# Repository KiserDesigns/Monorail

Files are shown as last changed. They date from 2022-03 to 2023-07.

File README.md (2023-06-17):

# Monorail V2

Version 2 is based on the RP2040 and has encoder positions on ESC, 1, and 6.

Plate files made up of the same outlines as are found in the Trashman Wiki, and enough permutations have been tested to be confident in their functionality.

More plate files can be found at https://www.minivanplate.xyz/

The "Combined" plates have support for all of the layouts from all three PCBs.

Vial firmware was built on this commit of the NCKiser fork of Vial, based on QMK v0.18 : https://github.com/NCKiser/vial-nckiser/commit/2a0371c2ef1b1343f7dda704ad11ff06da6e896c

# Build Guide

## What you need:
 - PCB (included)
 - Base (included)
 - Plate (included)
 - Hardware (included)
 - Philips (+) Screwdriver
 - Needle-nose Pliers (optional)



## Step 1: Standoffs
### There is the option to use Hull-mount, Tray-mount, or both at the same time!
### For Hull-mount, use brass washers on either side of the plate so the screw and 10mm standoff clamp firmly to the half-hole.

### Start with holding the screw and washer the top side, and then placing the washer and twisting on the standoff from the other side.



### Repeat this for the other 3 Hull-mount standoffs.

### For Tray-mount, attach the 5mm standoffs and washers to the base first, using the washer on the standoff side, not the screw side.



### Repeat this for all 8 Tray-mount point, or exclude certain points based on your desired typing feel.


## Step 2: PCB Assembly
### If using Tray-mount, it makes sense to screw the PCB to the base first.

### Snap switches into the PCB through the plate, starting with the center and outside corners.

### This is what the final stackup should look like:


## Step 3: Optional Part Removal
### The top half-numrow can be optionally removed for a 4-row layout or to fit in standard minivan cases.
### The half-numrow on the PCB and Base can be broken by hand:






### The plate will need to be separated using needle-nose pliers:





### If not using Hull-mount, the extra tabs can be removed using needle-nose pliers:





### If fitting the PCB into a V4N4G0N case, the right USB port may need to be removed.





### This will take a bit of force, and the USB port might be damaged while removing. That is okay.


## Stem 4: Firmware
### Vial firmware is pre-flashed on each PCB, and the default layout is hosted here.

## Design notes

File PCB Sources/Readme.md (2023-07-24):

Open in Kidac 6.0.10 or newer

Production files may need to be tweaked or re-computed before ordering from a PCB fabricator. Please use at your own risk, there is no guarantee of functionality.

Feel free to reach out to NoahK (kiserdesigns) on Discord (http://noahk.net) or through the Contact page on https://KiserDesigns.com if you would like help ordering these for yourself.

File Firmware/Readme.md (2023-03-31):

The keymap in the precompiled .uf2 is all KC_TRANS. Use Vial to configure your keymap.

DefaultLayout.vil is a Vial layout that contains most of the functionality that you need. Load this onto your board using Vial for a good starting point.

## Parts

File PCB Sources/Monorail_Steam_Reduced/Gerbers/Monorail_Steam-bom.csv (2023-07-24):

Id | Designator | Package | Quantity | Designation | Supplier and ref
1 | MX7,MX8,MX9,MX10,MX11,MX12,MX13,MX14,MX15,MX16,MX17,MX20,MX21,MX22,MX23,MX24,MX25,MX26,MX27,MX28,MX29,MX32,MX33,MX34,MX35,MX36,MX37,MX38,MX39,MX40,MX41,MX42,MX2,MX3,MX4,MX5,MX6,MX57,MX51,MX54,MX46,MX1,MX47 | MXOnly-1U-Hotswap | 43 | MX-NoLED
2 | MX18,MX31 | MXOnly-1.75U-Hotswap | 2 | MX-NoLED
3 | MX19,MX50,MX52,MX49,MX53,MX48 | MXOnly-1.25U-Hotswap | 6 | MX-NoLED
4 | MX30 | MXOnly-1.5U-Hotswap | 1 | MX-NoLED
5 | REF**,REF**,REF**,REF**,REF**,REF**,REF**,REF** | breakaway-mousebites | 8 | breakaway-mousebites
6 | MX44 | MXOnly-6.25U-Hotswap-ReversedStabilizers | 1 | MX-NoLED
7 | J10,J7 | PinHeader_1x09_P2.54mm_Vertical | 2 | Conn_01x09
8 | J9,J8 | PinHeader_1x05_P2.54mm_Vertical | 2 | Conn_01x05
9 | D55,D53,D54 | LED_D3.0mm | 3 | LED
10 |  |  | 1
11 | MX58,MX43 | MXOnly-3U-Hotswap-ReversedStabilizers | 2 | MX-NoLED
12 | SW3,SW2,SW1 | RotaryEncoder_Alps_EC11E-Switch_Vertical_H20mm | 3 | RotaryEncoder_Switch
13 | H1 | Minivan-reference | 1 | MountingHole_Pad
14 | MX45 | MXOnly-2.75U-Hotswap | 1 | MX-NoLED
15 | F1 | Fuse_1206_3216Metric | 1 | 500mA
16 | J1,J2 | USB_C_Receptacle_HRO_TYPE-C-31-M-12 | 2 | USB_C_Receptacle_USB2.0
17 | R4,R3,R1,R2 | R_0603_1608Metric | 4 | 5.1k
18 | R6,R7 | R_0402_1005Metric | 2 | 27
19 | U1 | SOT-23-6 | 1 | SRV05-4
20 | D33,D9,D27,D8,D28,D14,D18,D13,D16,D3,D51,D34,D44,D7,D22,D6,D11,D48,D41,D45,D52,D12,D17,D24,D47,D36,D30,D38,D31,D39,D10,D20,D1,D26,D4,D15,D2,D23,D40,D21,D50,D43,D25,D19,D29,D32,D35,D5,D37,D42 | D_SOD-123 | 50 | D_Small
21 | C9,C16,C10,C12,C18,C14,C15,C20,C17,C13,C19,C11 | C_0603_1608Metric | 12 | 0.1uF
22 | SWD1 | PinHeader_1x03_P2.54mm_Vertical | 1 | Conn_01x03_Female
23 | R14,R12 | R_0402_1005Metric | 2 | 1k
24 | D65,D61,D63,D66,D59,D58,D64,D62,D67,D60,D56,D57 | LED_WS2812B_2020 | 12 | WS2812B
25 | C6,C27 | C_0402_1005Metric | 2 | 30p
26 | C8,C28,C26,C22,C24,C21,C23,C7,C25 | C_0402_1005Metric | 9 | 100n
27 | J6 | PinHeader_1x03_P2.54mm_Vertical | 1 | Conn_01x03_Male
28 | R13 | R_0603_1608Metric | 1 | -10k
29 | R11,R9,R10 | R_0603_1608Metric | 3 | 470
30 | C2,C1,C4 | C_0402_1005Metric | 3 | 10u
31 | C5,C3 | C_0402_1005Metric | 2 | 1u
32 | SWR1,SWR2 | SW_SPST_TL3342 | 2 | SW_SPST
33 | R5 | R_0402_1005Metric | 1 | 5.1k
34 | U3 | QFN40P700X700X90-57N | 1 | RP2040TR7
35 | J4 | PinHeader_1x04_P2.54mm_Vertical | 1 | Conn_01x04_Male
36 | U4 | SOIC-8_5.23x5.23mm_P1.27mm | 1 | W25Q128JVS
37 | J5 | JST_SH_SM04B-SRSS-TB_1x04-1MP_P1.00mm_Horizontal | 1 | Conn_01x04_Female
38 | JP1 | SolderJumper-2_P1.3mm_Bridged2Bar_Pad1.0x1.5mm | 1 | SolderJumper_2_Bridged
39 | U2 | SOT-23 | 1 | XC6206PxxxMR
40 | Y1 | Crystal_SMD_3225-4Pin_3.2x2.5mm | 1 | Crystal_GND24_Small

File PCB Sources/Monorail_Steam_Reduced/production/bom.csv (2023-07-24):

Designator | Footprint | Quantity | Value | LCSC Part #
 |  | 1
C1, C2, C8 | 0402 | 3 | 10u
C10, C23, C24, C25, C26, C27, C28, C4, C5, C6, C7, C9 | 0603 | 12 | 0.1uF
C11, C12, C15, C16, C17, C18, C20, C21, C3 | 0402 | 9 | 100n
C13, C14 | 0402 | 2 | 1u
C19, C22 | 0402 | 2 | 30p
D1, D2, D3 | LED_D3.0mm | 3 | LED
D10, D11, D12, D13, D14, D15, D16, D17, D18, D19, D20, D21, D28, D29, D30, D31, D32, D33, D34, D35, D36, D37, D38, D39, D4, D40, D41, D42, D43, D44, D45, D46, D47, D48, D49, D5, D50, D51, D58, D59, D6, D60, D61, D62, D63, D64, D65, D7, D8, D9 | D_SOD-123 | 50 | D_Small
D22, D23, D24, D25, D26, D27, D52, D53, D54, D55, D56, D57 | LED_WS2812B_2020 | 12 | WS2812B
F1 | 1206 | 1 | 500mA
H1 | Minivan-reference | 1 | MountingHole_Pad
J1, J4 | PinHeader_1x05_P2.54mm_Vertical | 2 | Conn_01x05
J2, J3 | PinHeader_1x09_P2.54mm_Vertical | 2 | Conn_01x09
J5, J6 | USB_C_Receptacle_HRO_TYPE-C-31-M-12 | 2 | USB_C_Receptacle_USB2.0
J7 | JST_SH_SM04B-SRSS-TB_1x04-1MP_P1.00mm_Horizontal | 1 | Conn_01x04_Female
J8 | PinHeader_1x04_P2.54mm_Vertical | 1 | Conn_01x04_Male
J9 | PinHeader_1x03_P2.54mm_Vertical | 1 | Conn_01x03_Male
JP1 | SolderJumper-2_P1.3mm_Bridged2Bar_Pad1.0x1.5mm | 1 | SolderJumper_2_Bridged
MX1, MX10, MX11, MX12, MX13, MX14, MX15, MX16, MX17, MX18, MX19, MX2, MX21, MX22, MX23, MX24, MX25, MX26, MX27, MX28, MX29, MX3, MX31, MX32, MX33, MX34, MX35, MX36, MX37, MX38, MX39, MX4, MX40, MX41, MX44, MX45, MX5, MX52, MX53, MX56, MX6, MX8, MX9 | MXOnly-1U-Hotswap | 43 | MX-NoLED
MX20 | MXOnly-1.5U-Hotswap | 1 | MX-NoLED
MX30, MX43, MX46, MX51, MX54, MX55 | MXOnly-1.25U-Hotswap | 6 | MX-NoLED
MX42, MX7 | MXOnly-1.75U-Hotswap | 2 | MX-NoLED
MX47, MX50 | MXOnly-3U-Hotswap-ReversedStabilizers | 2 | MX-NoLED
MX48 | MXOnly-6.25U-Hotswap-ReversedStabilizers | 1 | MX-NoLED
MX49 | MXOnly-2.75U-Hotswap | 1 | MX-NoLED
R1, R2, R5 | 0603 | 3 | 470
R10, R11 | 0402 | 2 | 27
R12 | 0402 | 1 | 5.1k
R13, R9 | 0402 | 2 | 1k
R3, R4, R6, R7 | 0603 | 4 | 5.1k
R8 | 0603 | 1 | -10k
SW1, SW2, SW3 | RotaryEncoder_Alps_EC11E-Switch_Vertical_H20mm | 3 | RotaryEncoder_Switch
SWD1 | PinHeader_1x03_P2.54mm_Vertical | 1 | Conn_01x03_Female
SWR1, SWR2 | SW_SPST_TL3342 | 2 | SW_SPST
U1 | SOT-23-6 | 1 | SRV05-4
U2 | SOT-23 | 1 | XC6206PxxxMR
U3 | SOIC-8_5.23x5.23mm_P1.27mm | 1 | W25Q128JVS
U4 | QFN40P700X700X90-57N | 1 | RP2040TR7
Y1 | Crystal_SMD_3225-4Pin_3.2x2.5mm | 1 | Crystal_GND24_Small

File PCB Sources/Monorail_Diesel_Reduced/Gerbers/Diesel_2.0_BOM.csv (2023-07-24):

Designator | Footprint | Quantity | Value | LCSC Part #
R10, R11 | 402 | 2 | 27 | C25092
R1, R2, R5 | 603 | 3 | 470 | C23151
R8 | 603 | 1 | -10k
C10, C23, C24, C25, C26, C27, C28, C4, C5, C6, C7, C9 | 603 | 12 | 0.1uF | C14663
C11, C12, C15, C16, C17, C18, C20, C21, C3 | 402 | 9 | 100n | C307331
C1, C2, C8 | 402 | 3 | 10u | C15525
R13, R9 | 402 | 2 | 1k | C11702
C13, C14 | 402 | 2 | 1u | C52923
C19, C22 | 402 | 2 | 30p | C1570
R12 | 402 | 1 | 5.1k | C25905
R3, R4, R6, R7 | 603 | 4 | 5.1k | C23186
F1 | 1206 | 1 | 500mA | C70076
Y1 | Crystal_SMD_3225-4Pin_3.2x2.5mm | 1 | Crystal_GND24_Small | C9002
D10, D11, D12, D13, D14, D15, D16, D17, D18, D19, D20, D21, D28, D29, D30, D31, D32, D33, D34, D35, D36, D37, D38, D39, D4, D40, D41, D42, D43, D44, D45, D46, D47, D48, D49, D5, D50, D51, D58, D59, D6, D60, D61, D62, D63, D64, D65, D66, D67, D7, D8, D9 | D_SOD-123 | 52 | D_Small | C81598
MX1, MX10, MX11, MX12, MX13, MX14, MX15, MX16, MX17, MX18, MX19, MX2, MX21, MX22, MX23, MX24, MX25, MX26, MX27, MX28, MX29, MX3, MX31, MX32, MX33, MX34, MX35, MX36, MX37, MX38, MX39, MX4, MX40, MX41, MX43, MX45, MX5, MX51, MX53, MX55, MX57, MX6, MX8, MX9 | MXOnly-1U-Hotswap | 44 | MX-NoLED | C5156480
MX20, MX46, MX47, MX54 | MXOnly-1.5U-Hotswap | 4 | MX-NoLED | C5156480
MX30, MX48, MX52, MX56 | MXOnly-1.25U-Hotswap | 4 | MX-NoLED | C5156480
MX42, MX44, MX7 | MXOnly-1.75U-Hotswap | 3 | MX-NoLED | C5156480
MX49 | MXOnly-2U-Hotswap-ReversedStabilizers | 1 | MX-NoLED | C5156480
MX50 | MXOnly-2.25U-Hotswap-ReversedStabilizers | 1 | MX-NoLED | C5156480
U4 | QFN40P700X700X90-57N | 1 | RP2040TR7 | C2040
U1 | SOT-23-6 | 1 | SRV05-4 | C85364
SWR1, SWR2 | SW_SPST_TL3342 | 2 | SW_SPST | C318884
J5, J6 | USB_C_Receptacle_HRO_TYPE-C-31-M-12 | 2 | USB_C_Receptacle_USB2.0 | C165948
U3 | SOIC-8_5.23x5.23mm_P1.27mm | 1 | W25Q128JVS | C97521
D22, D23, D24, D25, D26, D27, D52, D53, D54, D55, D56, D57 | LED_WS2812B_2020 | 12 | WS2812B | C2976072
U2 | SOT-23 | 1 | XC6206PxxxMR | C5446
 |  | 1

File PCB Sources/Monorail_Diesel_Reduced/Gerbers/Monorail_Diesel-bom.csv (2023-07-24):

Id | Designator | Package | Quantity | Designation | Supplier and ref
1 | MX7,MX8,MX9,MX10,MX11,MX12,MX13,MX14,MX15,MX16,MX17,MX20,MX21,MX22,MX23,MX24,MX25,MX26,MX27,MX28,MX29,MX32,MX33,MX34,MX35,MX36,MX37,MX38,MX39,MX40,MX41,MX42,MX2,MX3,MX4,MX5,MX6,MX57,MX54,MX58,MX53,MX45,MX1,MX46 | MXOnly-1U-Hotswap | 44 | MX-NoLED
2 | MX18,MX31,MX50 | MXOnly-1.75U-Hotswap | 3 | MX-NoLED
3 | MX19,MX48,MX53,MX45 | MXOnly-1.25U-Hotswap | 4 | MX-NoLED
4 | MX30,MX49,MX54,MX55 | MXOnly-1.5U-Hotswap | 4 | MX-NoLED
5 | REF**,REF**,REF**,REF**,REF**,REF**,REF**,REF** | breakaway-mousebites | 8 | breakaway-mousebites
6 | MX47 | MXOnly-2U-Hotswap-ReversedStabilizers | 1 | MX-NoLED
7 | J10,J7 | PinHeader_1x09_P2.54mm_Vertical | 2 | Conn_01x09
8 | J9,J8 | PinHeader_1x05_P2.54mm_Vertical | 2 | Conn_01x05
9 | D55,D53,D54 | LED_D3.0mm | 3 | LED
10 |  |  | 1
11 | SW3,SW2,SW1 | RotaryEncoder_Alps_EC11E-Switch_Vertical_H20mm | 3 | RotaryEncoder_Switch
12 | MX46 | MXOnly-2.25U-Hotswap-ReversedStabilizers | 1 | MX-NoLED
13 | H1 | Minivan-reference | 1 | MountingHole_Pad
14 | F1 | Fuse_1206_3216Metric | 1 | 500mA
15 | J1,J2 | USB_C_Receptacle_HRO_TYPE-C-31-M-12 | 2 | USB_C_Receptacle_USB2.0
16 | R4,R3,R1,R2 | R_0603_1608Metric | 4 | 5.1k
17 | R6,R7 | R_0402_1005Metric | 2 | 27
18 | U1 | SOT-23-6 | 1 | SRV05-4
19 | D33,D9,D27,D8,D28,D14,D18,D13,D16,D3,D51,D34,D44,D7,D22,D6,D11,D48,D41,D45,D52,D12,D17,D24,D47,D36,D30,D38,D31,D39,D46,D10,D20,D1,D49,D26,D4,D15,D2,D23,D40,D21,D50,D43,D25,D19,D29,D32,D35,D5,D37,D42 | D_SOD-123 | 52 | D_Small
20 | C9,C16,C10,C12,C18,C14,C15,C20,C17,C13,C19,C11 | C_0603_1608Metric | 12 | 0.1uF
21 | SWD1 | PinHeader_1x03_P2.54mm_Vertical | 1 | Conn_01x03_Female
22 | R14,R12 | R_0402_1005Metric | 2 | 1k
23 | D65,D61,D63,D66,D59,D58,D64,D62,D67,D60,D56,D57 | LED_WS2812B_2020 | 12 | WS2812B
24 | C6,C27 | C_0402_1005Metric | 2 | 30p
25 | C8,C28,C26,C22,C24,C21,C23,C7,C25 | C_0402_1005Metric | 9 | 100n
26 | J6 | PinHeader_1x03_P2.54mm_Vertical | 1 | Conn_01x03_Male
27 | R13 | R_0603_1608Metric | 1 | -10k
28 | R11,R9,R10 | R_0603_1608Metric | 3 | 470
29 | C2,C1,C4 | C_0402_1005Metric | 3 | 10u
30 | C5,C3 | C_0402_1005Metric | 2 | 1u
31 | SWR1,SWR2 | SW_SPST_TL3342 | 2 | SW_SPST
32 | R5 | R_0402_1005Metric | 1 | 5.1k
33 | U3 | QFN40P700X700X90-57N | 1 | RP2040TR7
34 | J4 | PinHeader_1x04_P2.54mm_Vertical | 1 | Conn_01x04_Male
35 | U4 | SOIC-8_5.23x5.23mm_P1.27mm | 1 | W25Q128JVS
36 | J5 | JST_SH_SM04B-SRSS-TB_1x04-1MP_P1.00mm_Horizontal | 1 | Conn_01x04_Female
37 | JP1 | SolderJumper-2_P1.3mm_Bridged2Bar_Pad1.0x1.5mm | 1 | SolderJumper_2_Bridged
38 | U2 | SOT-23 | 1 | XC6206PxxxMR
39 | Y1 | Crystal_SMD_3225-4Pin_3.2x2.5mm | 1 | Crystal_GND24_Small

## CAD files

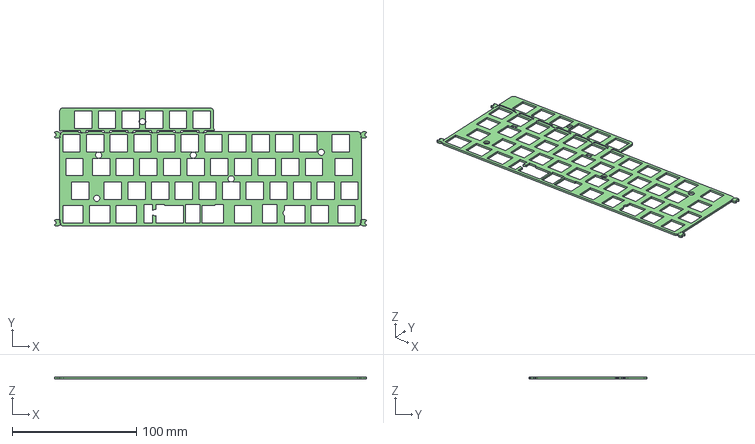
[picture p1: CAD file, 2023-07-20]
3D Models/Hull_V4N_Tray_Plate.step
251.2 x 95.2 x 1.60 mm

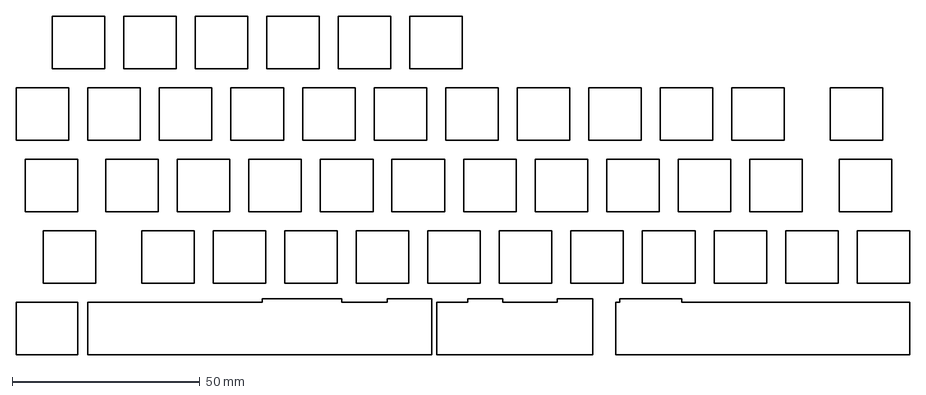
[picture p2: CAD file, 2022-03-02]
Plate DXFs/Cutouts Only/m0n0rail_universal.dxf
237.8 x 90.2 mm

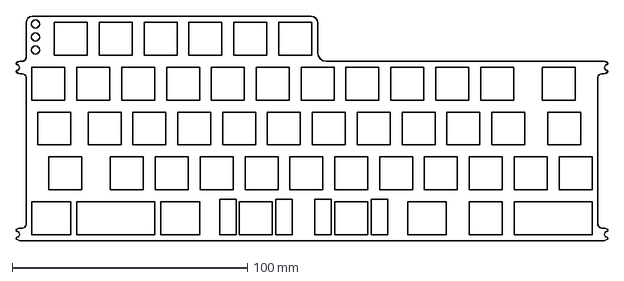
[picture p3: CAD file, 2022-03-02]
Plate DXFs/Diesel Hullagon.dxf
251.3 x 95.2 mm

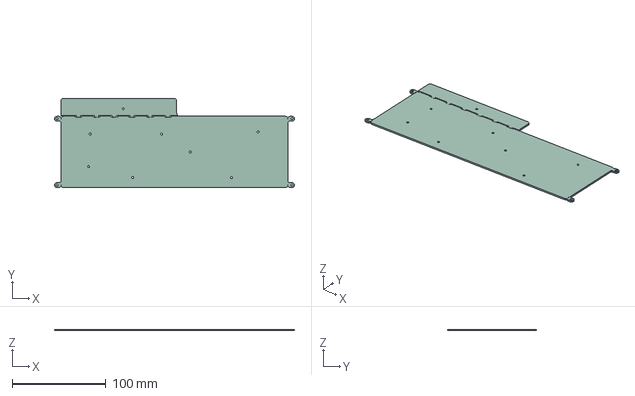
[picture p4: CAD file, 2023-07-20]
3D Models/Hull_V4N_Tray_Base.step
256.2 x 95.3 x 1.58 mm

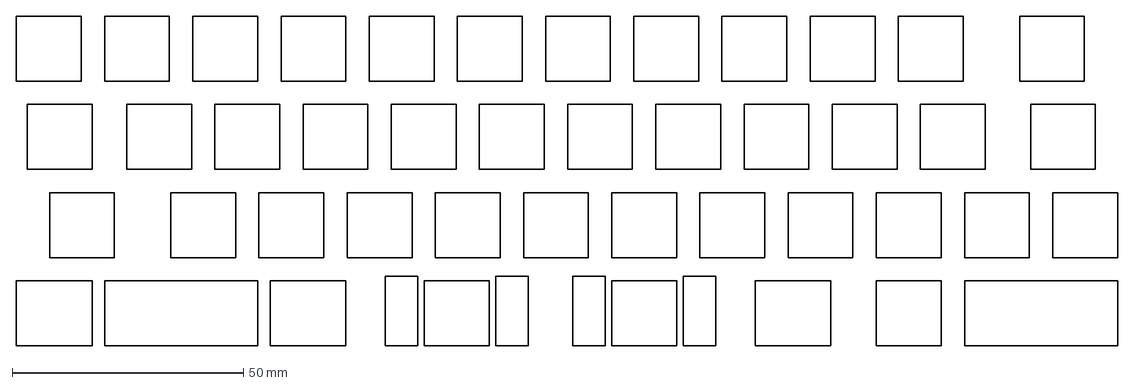
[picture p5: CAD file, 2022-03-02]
Plate DXFs/Cutouts Only/monorail_diesel.dxf
237.8 x 71.1 mm

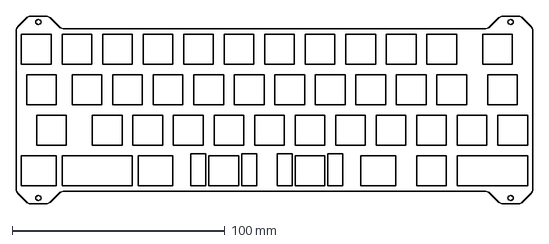
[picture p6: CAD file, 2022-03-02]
Plate DXFs/Diesel Coriander.dxf
242.9 x 88.2 mm

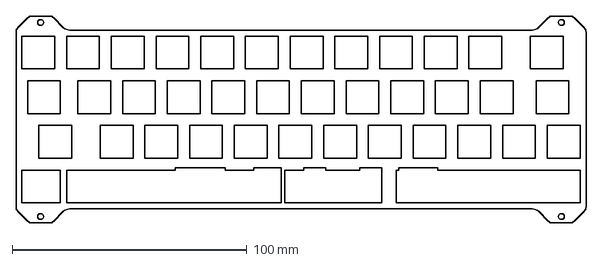
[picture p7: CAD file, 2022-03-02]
Plate DXFs/Combined Coriander.dxf
242.9 x 88.2 mm

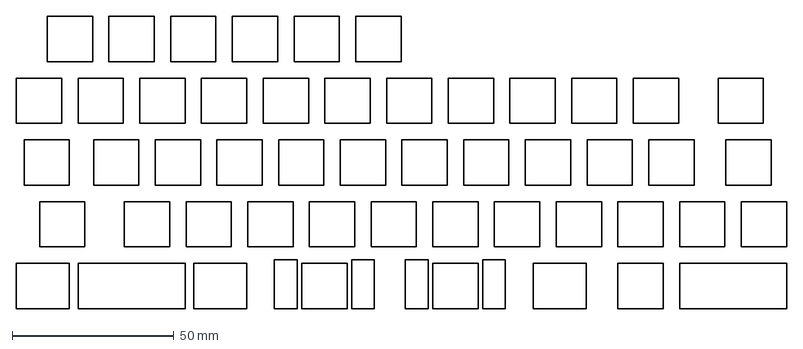
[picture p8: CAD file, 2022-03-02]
Plate DXFs/Cutouts Only/m0n0rail_diesel.dxf
237.8 x 90.2 mm

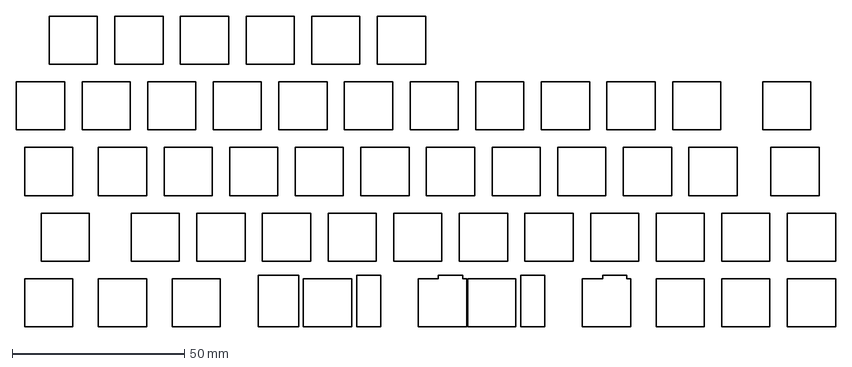
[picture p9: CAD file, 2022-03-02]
Plate DXFs/Cutouts Only/m0n0rail_jet.dxf
237.8 x 90.2 mm

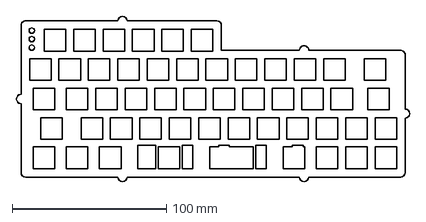
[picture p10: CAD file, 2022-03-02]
Plate DXFs/Jet Vanagon.dxf
255.0 x 107.3 mm

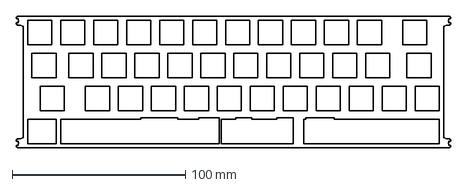
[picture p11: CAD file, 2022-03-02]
Plate DXFs/Combined Hull.dxf
251.3 x 76.2 mm

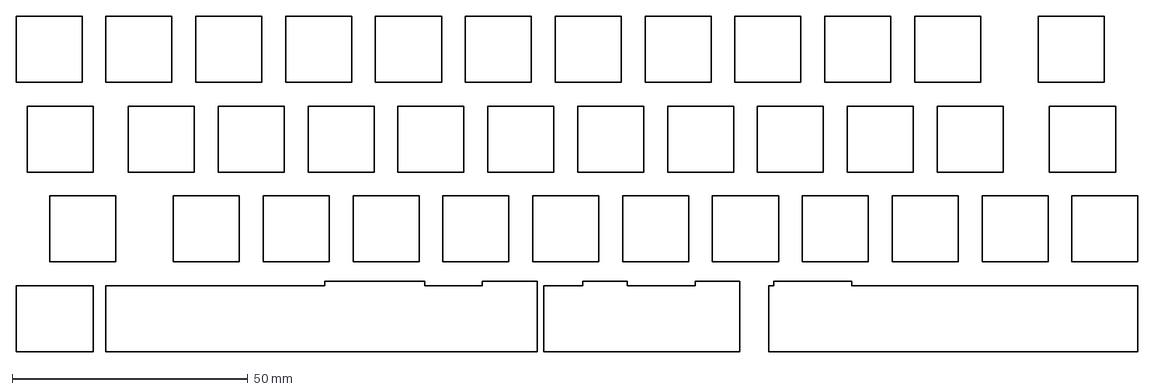
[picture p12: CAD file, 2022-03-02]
Plate DXFs/Cutouts Only/monorail_universal.dxf
237.8 x 71.1 mm

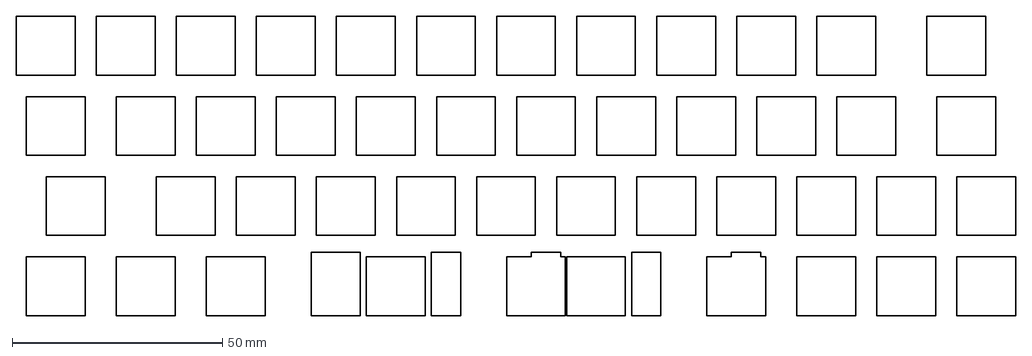
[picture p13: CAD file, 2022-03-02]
Plate DXFs/Cutouts Only/monorail_jet.dxf
237.8 x 71.1 mm

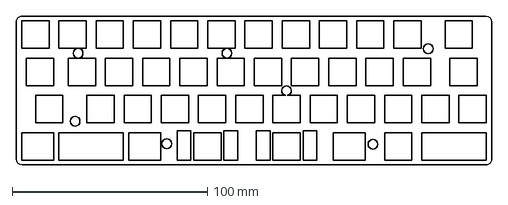
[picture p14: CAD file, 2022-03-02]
Plate DXFs/Diesel Tray Mount.dxf
243.4 x 76.2 mm

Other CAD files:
Plate DXFs/Cutouts Only/m0n0rail_steam.dxf
Plate DXFs/Jet Hullagon.dxf
Plate DXFs/Cutouts Only/monorail_steam.dxf
Plate DXFs/Diesel Vanagon.dxf
Plate DXFs/Combined Hullagon.dxf
Plate DXFs/Combined Tray Mount.dxf
Plate DXFs/Combined Vanagon.dxf
Plate DXFs/Diesel Hull.dxf
Plate DXFs/Jet Coriander.dxf
Plate DXFs/Jet Hull.dxf
Plate DXFs/Jet Tray Mount.dxf
Plate DXFs/Steam Coriander.dxf
Plate DXFs/Steam Hull.dxf
Plate DXFs/Steam Hullagon.dxf
Plate DXFs/Steam Tray Mount.dxf
Plate DXFs/Steam Vanagon.dxf

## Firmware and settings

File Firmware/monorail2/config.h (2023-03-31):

/*
Copyright 2021 Noah Kiser (contact@kiserdesigns.com)

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
You should have received a copy of the GNU General Public License
along with this program.  If not, see <http://www.gnu.org/licenses/>.
*/

#ifndef CONFIG_H
#define CONFIG_H

#include "config_common.h"

#define VENDOR_ID       0x4B44
#define PRODUCT_ID      0x4D72
#define DEVICE_VER 	0x0002
#define MANUFACTURER    Kiser Designs
#define PRODUCT         Monorail V2

#define MATRIX_ROWS 5
#define MATRIX_COLS 12

#define LED0_PIN GP25
#define LED1_PIN GP26
#define LED2_PIN GP27

// flip the 0 to a 1 to go back to a regular caps lock indicator, or remove these 2 lines entirely to eliminate the caps lock indicator function
#define LED_CAPS_LOCK_PIN GP25
#define LED_PIN_ON_STATE 0

#define MATRIX_ROW_PINS { GP9, GP1, GP4, GP5, GP28 }
#define MATRIX_COL_PINS { GP23, GP22, GP21, GP20, GP19, GP18, GP17, GP16, GP10, GP11, GP6, GP0 }

#define DIODE_DIRECTION COL2ROW

#define TAPPING_TERM 200

#define ENCODERS_PAD_A { GP12 }
#define ENCODERS_PAD_B { GP24 }

#define ENCODER_RESOLUTIONS { 4 }

#define RGB_DI_PIN GP29
#define DRIVER_LED_TOTAL 12
#define RGB_MATRIX_LED_COUNT 12
#define RGBLED_NUM 12

#define RGB_MATRIX_EFFECTS
#define RGB_MATRIX_FRAMEBUFFER_EFFECTS
#define RGB_MATRIX_KEYPRESSES

#define ENABLE_RGB_MATRIX_ALPHAS_MODS
#define ENABLE_RGB_MATRIX_GRADIENT_UP_DOWN
#define ENABLE_RGB_MATRIX_GRADIENT_LEFT_RIGHT
#define ENABLE_RGB_MATRIX_BREATHING
#define ENABLE_RGB_MATRIX_BAND_SAT
#define ENABLE_RGB_MATRIX_BAND_VAL
#define ENABLE_RGB_MATRIX_BAND_PINWHEEL_SAT
#define ENABLE_RGB_MATRIX_BAND_PINWHEEL_VAL
#define ENABLE_RGB_MATRIX_BAND_SPIRAL_SAT
#define ENABLE_RGB_MATRIX_BAND_SPIRAL_VAL
#define ENABLE_RGB_MATRIX_CYCLE_ALL
#define ENABLE_RGB_MATRIX_CYCLE_LEFT_RIGHT
#define ENABLE_RGB_MATRIX_CYCLE_UP_DOWN
#define ENABLE_RGB_MATRIX_RAINBOW_MOVING_CHEVRON
#define ENABLE_RGB_MATRIX_CYCLE_OUT_IN
#define ENABLE_RGB_MATRIX_CYCLE_OUT_IN_DUAL
#define ENABLE_RGB_MATRIX_CYCLE_PINWHEEL
#define ENABLE_RGB_MATRIX_CYCLE_SPIRAL
#define ENABLE_RGB_MATRIX_DUAL_BEACON
#define ENABLE_RGB_MATRIX_RAINBOW_BEACON
#define ENABLE_RGB_MATRIX_RAINBOW_PINWHEELS
#define ENABLE_RGB_MATRIX_RAINDROPS
#define ENABLE_RGB_MATRIX_JELLYBEAN_RAINDROPS
#define ENABLE_RGB_MATRIX_HUE_BREATHING
#define ENABLE_RGB_MATRIX_HUE_PENDULUM
#define ENABLE_RGB_MATRIX_HUE_WAVE
#define ENABLE_RGB_MATRIX_PIXEL_FRACTAL
#define ENABLE_RGB_MATRIX_PIXEL_FLOW
#define ENABLE_RGB_MATRIX_PIXEL_RAIN

#define ENABLE_RGB_MATRIX_TYPING_HEATMAP
#define ENABLE_RGB_MATRIX_DIGITAL_RAIN

#define ENABLE_RGB_MATRIX_SOLID_REACTIVE_SIMPLE
#define ENABLE_RGB_MATRIX_SOLID_REACTIVE
#define ENABLE_RGB_MATRIX_SOLID_REACTIVE_WIDE
#define ENABLE_RGB_MATRIX_SOLID_REACTIVE_MULTIWIDE
#define ENABLE_RGB_MATRIX_SOLID_REACTIVE_CROSS
#define ENABLE_RGB_MATRIX_SOLID_REACTIVE_MULTICROSS
#define ENABLE_RGB_MATRIX_SOLID_REACTIVE_NEXUS
#define ENABLE_RGB_MATRIX_SOLID_REACTIVE_MULTINEXUS
#define ENABLE_RGB_MATRIX_SPLASH
#define ENABLE_RGB_MATRIX_MULTISPLASH
#define ENABLE_RGB_MATRIX_SOLID_SPLASH
#define ENABLE_RGB_MATRIX_SOLID_MULTISPLASH

#define RP2040_BOOTLOADER_DOUBLE_TAP_RESET
#define RP2040_BOOTLOADER_DOUBLE_TAP_RESET_TIMEOUT 500U

#endif

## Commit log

2022-03-02 Added Plate Files
2022-03-02 Added Cutouts Only
    [m0n0rail_diesel.dxf, m0n0rail_jet.dxf, m0n0rail_steam.dxf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]
2022-03-30 Added Prototype PCB RGB notes to Readme
2022-07-25 removed json whitespace, name, vid and pid. layer count is now 5
2023-07-24 add base and plate files
    [Hull_V4N_Tray_Base-B_Cu.gbr, Hull_V4N_Tray_Base-B_Mask.gbr, Hull_V4N_Tray_Base-B_Paste.gbr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]
2023-07-24 add diesel PCB files
    [Diesel_2.0_BOM.csv, Diesel_2.0_BOM_OLD.csv, Monorail_Diesel-bom.csv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]
2023-07-24 add jet PCB files
    [Jet_2.0_BOM.csv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]
2023-07-24 add steam PCB files
    [Monorail_Jet2-BOM.csv, Monorail_Steam-bom.csv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]

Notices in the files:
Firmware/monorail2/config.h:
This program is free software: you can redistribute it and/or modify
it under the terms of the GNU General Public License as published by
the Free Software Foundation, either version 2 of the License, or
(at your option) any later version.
